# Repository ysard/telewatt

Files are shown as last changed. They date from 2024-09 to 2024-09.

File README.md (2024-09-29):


[][cc-by-nc-sa]

# TeleWatt

## Projet et avant-propos

Ce circuit a pour but de traiter les informations émises depuis
la sortie Télé-Information Client (TIC) des compteurs
d'électricité installés par le fournisseur français Enedis.

La sortie TIC offre aux clients la possibilité d’être informés en temps réel
des grandeurs électriques mesurées (périodes tarifaires, contacts virtuels,
puissance instantanée, etc.).

Ce système avec son firmware interprète les données, les conserve sur un ESP8266
et/ou les envoie sur un serveur personnel. Ceci garantit une pleine maîtrise
de celles-ci sans passer par un prestataire **coûteux** et parfois opaque.

Par ailleurs, les pas de collecte de 1h ou 30 minutes sont déjà particulièrement
intrusifs s'ils ont été souscrits auprès du fournisseur.
Un pas de collecte plus court permit par les modules Téléinfo l'est encore plus.
Par ailleurs, les modules du commerce ne viennent en général jamais seuls :
ils peuvent être couplés à des mesures de température, d'humidité, etc.
Des économies sont promises, mais c'est surtout un profilage à l'usage de l'électricité
qui est obtenu.

## Circuit

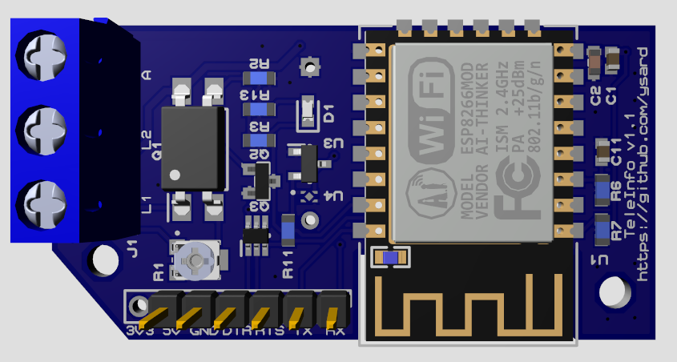
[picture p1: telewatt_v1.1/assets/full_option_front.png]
v1.1 front


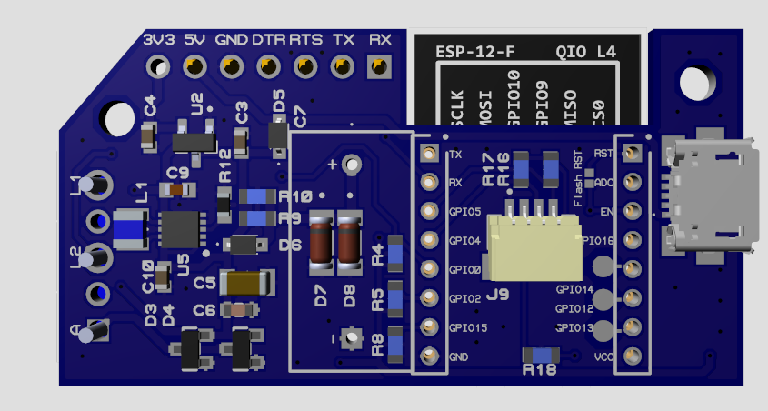
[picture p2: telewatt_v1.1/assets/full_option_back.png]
v1.1 back

Carte complète (circuit USB + condensateur; en pratique, un seul est nécessaire).

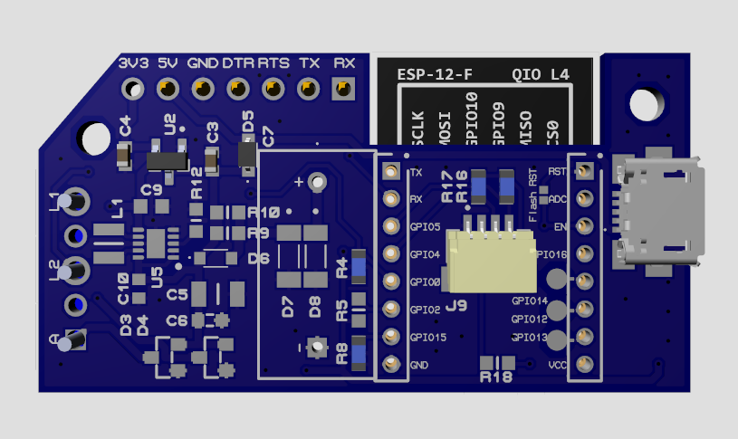
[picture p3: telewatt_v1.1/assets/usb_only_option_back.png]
v1.1 usb only


Carte non autonome avec circuit USB seul.

### Généralités

Le raccordement se fait sur le bornier du compteur comprenant 3 bornes (L1, L2, A).
La borne A permet la conception de circuits autoalimentés à l'aide d'un
super condensateur garantissant une certaine autonomie (mais pas un fonctionnement continu).

Les anciens compteurs avec seulement les bornes L1 et L2 sont compatibles,
à condition d'opter pour la version du circuit requérant une alimentation externe (USB - 5V).

La carte se charge à 100% en 11 minutes et autorise 4 minutes d'autonomie
avec un condensateur de 3.5F.
Un tel condensateur est très largement surdimensionné pour une brève
connexion MQTT toutes les 5 minutes.

Les composants sont choisis pour être courants, peu coûteux et faciles
à utiliser lors d'un assemblage manuel.

### Fonctionnalités

- ESP8266 1Mb ou 4Mb
- Autoalimenté
- Veille profonde
- Suivi de tension du condensateur
- Broches UART accessibles : GND, 3V3, 5V, RX, TX, DTR, RST
(Notes : **ne pas utiliser simultanément les broches 3V3 et 5V**; la broche 3V3 **n'est pas protégée**; bien veiller à fournir cette tension exacte en cas d'utilisation).
- GPIOs exposés : 12, 13, 14
- Connexion au compteur via un bornier ou des broches

Options :

- LED optionnelle pour visualiser la réception Téléinfo
(couper la piste droite du pad "Auto TIC LED", et souder le pad central avec celui de gauche).
- Emplacement QWIIC I2C
- Circuit d'alimentation USB

### Pinout

Pin     | Fonction
|:--- |:--- |
ADC     | Surveillance de la tension du condensateur
GPIO0   | Démarrage automatique en mode flash
GPIO1   | UART TX
GPIO2   | Résistance de Pull-up / tirage
GPIO3   | UART RX / Téléinfo RX
GPIO4   | I2C SDA
GPIO5   | I2C SCL
GPIO7   | Correctif optionnel deepsleep pour ESP8266 [défaillants](https://github.com/esp8266/Arduino/issues/6007)
GPIO12  | Pad libre
GPIO13  | Pad libre
GPIO14  | Gestion optionnelle de la LED TIC, pad libre
GPIO15  | Résistance de Pull-down / rappel
GPIO16  | Réveil deepsleep

### Datasheet

python test coverage

### Historique des changements

#### v1.1

- Réduction de la taille: passe entièrement dans la coque du Linky
- Ajout R18: Correctif ESP8266 défaillants sur le PCB
- Correction du circuit de flash automatique non fonctionnel
- Suppression connecteur Mini-USB
- Doublement optionnel des zener D7-D8
- Pad optionnel de gestion de la LED TIC
- Pad optionnel de gestion du flash sur le pin RST au lieu du pin EN
- Ajout broche 5V
- Ajout circuit de surveillance de la tension du condensateur

## Firmware

Le circuit est compatible avec l'extension Teleinfo de Tasmota :
[Tasmota - Teleinfo](https://tasmota.github.io/docs/Teleinfo/).

Mais aussi avec une version non officielle améliorée :
<https://github.com/NicolasBernaerts/tasmota/tree/master/teleinfo)>.

ESPHome est probablement aussi supporté.

Tous ces firmwares sont compatibles avec HomeAssistant.

### Procédure de flash

Matériel requis : interface USB vers TTL/UART.
Exemples de chipsets : CH341 CH340, CP2102, FT232RL, etc.

Installation d'`esptool` via le gestionnaire système ou Python :

    $ apt install esptool

ou :

    $ pip install esptool

Envoi du binaire (pré)compilé :

    $ esptool write_flash -fs 4MB -fm dout 0x0 tasmota-teleinfo-**.bin

Où `**` correspond au type d'ESP8266 utilisé (normalement 4M).
Toutefois pour un usage avec HomeAssistant, les options incluses dans cette version
(courbes et historique) sont inutiles; opter pour la version 1M
ou une compilation personnalisée est donc envisageable.

Les mises à jour ultérieures pourront se faire en ligne (Over The Air - OTA).

## Configuration

Voici l'essentiel des modifications pour Tasmota + HomeAssistant.

Pour plus d'informations, voir les documentations complètes des firmwares respectifs :

- https://tasmota.github.io/docs/Teleinfo/#configure-gpios-for-teleinfo
- https://github.com/NicolasBernaerts/tasmota/tree/master/teleinfo#fonctionnalit%C3%A9s

Dès le branchement, l'ESP8266 démarre en mode configuration WiFi.
Si le condensateur est chargé, quelques minutes seront octroyées
pour faire les modifications requises.

### Configuration du WiFi

Sélectionner le point d'accès initié par le module et s'y connecter avec
un ordinateur ou un téléphone.

L'adresse de la page de configuration est `http://192.168.4.1`.
Renseigner le mot de passer réseau puis laisser l'appareil redémarrer.

### Configuration du module

Se connecter à l'appareil depuis le réseau WiFi du domicile
(rechercher son  adresse IP via les pages d'administration de la box
ou via `nmap -sP 192.168.1.0/24`).

Ne pas oublier de configurer la liaison MQTT (IP, port, login, mot de passe),
la connexion réseau (une IP fixe limite le temps passé hors veille)
et les options Téléinfo (mode standard vs historique, etc.).

L'essentiel des configurations se fait dans la console Tasmota.

Pour configurer les GPIOs et le type de module simplement en une fois, voici le
[template à importer](https://tasmota.github.io/docs/Templates/#importing-templates) :

    {"NAME":"TeleWatt","GPIO":[1,1,1,5152,1,1,1,1,1,1,1,1,1,1],"FLAG":0,"BASE":18}

- Configuration du type de module :
Type de module : "Generic(18)" (i.e remplacer "Generic (0)")

- Configuration des GPIOs :

    - Config données: GPIO3 (RXD) = "TInfo RX"
    - Config deepsleep: GPIO16 = "None"

- Activer l'auto-découverte des entités HomeAssistant :

    $ hass_enable 1

- Désactiver le serveur TCP :

    $ tcp_stop

- Désactiver l'affichage des données sur la page d'accueil :

    $ websensor3 0

- Durée de mise en sommeil (le module entrera en veille 60s après cette commande) :

    $ deepsleeptime xxx   (<= ~30s, != 300s)

## Autre documentation

La démodulation Téléinfo est tirée du travail de Charles Hallard :

- [Démystifier le décodage Téléinformation](http://hallard.me/demystifier-la-teleinfo/)
- [Récupérer les données de son compteur linky](https://miniprojets.net/index.php/2019/06/28/recuperer-les-donnees-de-son-compteur-linky/)

## Licence

L'interface matérielle est publiée sous licence [Creative Commons CC BY-NC-SA 4.0][cc-by-nc-sa].

[cc-by-nc-sa]: http://creativecommons.org/licenses/by-nc-sa/4.0/
[cc-by-nc-sa-image]: https://licensebuttons.net/l/by-nc-sa/4.0/88x31.png
[cc-by-nc-sa-shield]: https://img.shields.io/badge/License-CC%20BY--NC--SA%204.0-lightgrey.svg

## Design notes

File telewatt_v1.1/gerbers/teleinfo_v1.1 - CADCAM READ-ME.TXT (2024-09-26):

LABCENTER PROTEUS TOOL INFORMATION FILE
=======================================

In case of difficulty, please e-mail support@labcenter.co.uk

Tool set up for Proteus layout 'teleinfo_v1.1.pdsprj'.
CADCAM generated at 18:34:03 on jeudi 26 septembre 2024.

File List
---------
Top Copper              : teleinfo_v1.1 - CADCAM Top Copper.GBR
Bottom Copper           : teleinfo_v1.1 - CADCAM Bottom Copper.GBR
Mechanical 1            : teleinfo_v1.1 - CADCAM Mechanical 1.GBR
Top Silk Screen         : teleinfo_v1.1 - CADCAM Top Silk Screen.GBR
Bottom Silk Screen      : teleinfo_v1.1 - CADCAM Bottom Silk Screen.GBR
Top Solder Resist       : teleinfo_v1.1 - CADCAM Top Solder Resist.GBR
Bottom Solder Resist    : teleinfo_v1.1 - CADCAM Bottom Solder Resist.GBR
Top SMT Paste           : teleinfo_v1.1 - CADCAM Top SMT Paste.GBR
Bottom SMT Paste        : teleinfo_v1.1 - CADCAM Bottom SMT Paste.GBR
Top Assembly            : teleinfo_v1.1 - CADCAM Top Assembly.GBR
Bottom Assembly         : teleinfo_v1.1 - CADCAM Bottom Assembly.GBR
Profile                 : teleinfo_v1.1 - CADCAM Profile.GBR
Drill, Unplated, 1-16   : teleinfo_v1.1 - CADCAM Drill TOP-BOT NonPlated.GBR
Drill, Plated, 1-16     : teleinfo_v1.1 - CADCAM Drill TOP-BOT Plated.GBR
Drill, Filled, 1-16     : teleinfo_v1.1 - CADCAM Drill TOP-BOT Filled and Plated.GBR
Netlist                 : teleinfo_v1.1 - CADCAM Netlist.IPC

Photoplotter Setup
------------------
Format: X2, ASCII, 4.3, metric, absolute, eob=*, LZO
Bounds: -6.72mm 6.16mm 17.89mm 53.37mm
Notes:  D=Diameter, S=Side, W=Width, H=Height, C=Chamfer, I=Index

D10	CIRCLE  D=0.254mm                                                         DRAW  Conductor
D11	CIRCLE  D=0.508mm                                                         DRAW  Conductor
D12	CIRCLE  D=0.305mm                                                         DRAW  Conductor
D13	CIRCLE  D=0.203mm                                                         DRAW  Conductor
D14	CIRCLE  D=0.6mm                                                           FLASH ViaPad
D15	RECT    W=1.2mm               H=2mm                                       FLASH SMDPad,CuDef
D16	RECT    W=2mm                 H=1.2mm                                     FLASH SMDPad,CuDef
D17	SQUARE  S=1.485mm                                                         FLASH ComponentPad
D18	CIRCLE  D=2.1mm                                                           FLASH ComponentPad
D19	RECT    W=2.1mm               H=1.45mm                                    FLASH SMDPad,CuDef
D70	RECT    W=0.889mm             H=1.016mm                                   FLASH SMDPad,CuDef
D71	RECT    W=0.991mm             H=0.94mm                                    FLASH SMDPad,CuDef
D20	RECT    W=0.94mm              H=0.991mm                                   FLASH SMDPad,CuDef
D21	RECT    W=0.81mm              H=0.94mm                                    FLASH SMDPad,CuDef
D22	SQUARE  S=0.889mm                                                         FLASH SMDPad,CuDef
D23	RECT    W=0.6mm               H=1.25mm                                    FLASH SMDPad,CuDef
D24	SQUARE  S=0.05mm                                                          FLASH SMDPad,CuDef
D25	PPAD    W=0.31mm              H=0.46mm              I=0                   FLASH SMDPad,CuDef
D26	PPAD    W=0.31mm              H=0.46mm              I=1                   FLASH SMDPad,CuDef
D27	PPAD    W=0.31mm              H=0.46mm              I=2                   FLASH SMDPad,CuDef
D28	PPAD    W=0.31mm              H=0.46mm              I=3                   FLASH SMDPad,CuDef
D29	PPAD    W=0.82mm              H=0.82mm              I=4                   FLASH SMDPad,CuDef
D72	CIRCLE  D=1.397mm                                                         FLASH ComponentPad
D73	SQUARE  S=1.397mm                                                         FLASH ComponentPad
D30	SQUARE  S=1.27mm                                                          FLASH ComponentPad
D31	CIRCLE  D=1.24mm                                                          FLASH ComponentPad
D32	SQUARE  S=1.2mm                                                           FLASH SMDPad,CuDef
D33	RECT    W=1.6mm               H=1.5mm                                     FLASH SMDPad,CuDef
D34	SQUARE  S=0.95mm                                                          FLASH SMDPad,CuDef
D35	CIRCLE  D=1.65mm                                                          FLASH OtherPad,Unknown
D36	RECT    W=1.15mm              H=0.45mm                                    FLASH SMDPad,CuDef
D37	SQUARE  S=1.65mm                                                          FLASH WasherPad
D38	CIRCLE  D=1.65mm                                                          FLASH ComponentPad
D39	RECT    W=0.9mm               H=1.3mm                                     FLASH SMDPad,CuDef
D40	RECT    W=1.3mm               H=0.9mm                                     FLASH SMDPad,CuDef
D41	CIRCLE  D=0.178mm                                                         DRAW  Profile
D42	CIRCLE  D=0.635mm                                                         DRAW  Conductor
D43	CIRCLE  D=0.381mm                                                         DRAW  Conductor
D44	PPAD    W=1.22mm              H=0.62mm              I=5                   FLASH SMDPad,CuDef
D45	RECT    W=1.13mm              H=1.72mm                                    FLASH SMDPad,CuDef
D46	RECT    W=0.9mm               H=0.8mm                                     FLASH SMDPad,CuDef
D47	PPAD    W=0.3mm               H=0.8mm               I=6                   FLASH SMDPad,CuDef
D48	PPAD    W=0.3mm               H=0.8mm               I=7                   FLASH SMDPad,CuDef
D49	RECT    W=2.1mm               H=1.3mm                                     FLASH SMDPad,CuDef
D50	RECT    W=1.02mm              H=0.96mm                                    FLASH SMDPad,CuDef
D51	RECT    W=0.9mm               H=0.95mm                                    FLASH SMDPad,CuDef
D52	RECT    W=1.82mm              H=1.05mm                                    FLASH SMDPad,CuDef
D53	RECT    W=0.85mm              H=2.2mm                                     FLASH SMDPad,CuDef
D54	RECT    W=0.8mm               H=0.9mm                                     FLASH SMDPad,CuDef
D55	RECT    W=0.4mm               H=1.35mm                                    FLASH SMDPad,CuDef
D56	RECT    W=2.1mm               H=1.6mm                                     FLASH SMDPad,CuDef
D57	RECT    W=1.8mm               H=1.9mm                                     FLASH SMDPad,CuDef
D58	SQUARE  S=1.9mm                                                           FLASH SMDPad,CuDef
D59	RECT    W=1.55mm              H=0.6mm                                     FLASH SMDPad,CuDef
D60	RECT    W=1.8mm               H=1.2mm                                     FLASH SMDPad,CuDef
D61	CIRCLE  D=1.5mm                                                           FLASH FiducialPad,Global
D62	CIRCLE  D=0.2mm                                                           DRAW  Material
D63	CIRCLE  D=0.178mm                                                         DRAW  Material
D64	CIRCLE  D=0.127mm                                                         DRAW  Material
D65	CIRCLE  D=0.127mm                                                         DRAW  NonMaterial
D66	CIRCLE  D=0.1mm                                                           DRAW  Material
D67	CIRCLE  D=0.076mm                                                         DRAW  NonMaterial
D68	CIRCLE  D=0.25mm                                                          DRAW  Material
D69	PPAD    W=1.2mm               H=2mm                 I=8                   FLASH Material
D74	PPAD    W=2mm                 H=1.2mm               I=9                   FLASH Material
D75	PPAD    W=1.585mm             H=1.585mm             I=10                  FLASH Material
D76	CIRCLE  D=2.2mm                                                           FLASH Material
D77	PPAD    W=2.1mm               H=1.45mm              I=11                  FLASH Material
D78	PPAD    W=1.143mm             H=1.27mm              I=12                  FLASH Material
D79	PPAD    W=0.991mm             H=0.94mm              I=13                  FLASH Material
D80	PPAD    W=0.94mm              H=0.991mm             I=14                  FLASH Material
D81	PPAD    W=0.81mm              H=0.94mm              I=15                  FLASH Material
D82	PPAD    W=1.143mm             H=1.143mm             I=16                  FLASH Material
D83	PPAD    W=0.6mm               H=1.25mm              I=17                  FLASH Material
D84	PPAD    W=0.05mm              H=0.05mm              I=18                  FLASH Material
D85	CIRCLE  D=1.651mm                                                         FLASH Material
D86	PPAD    W=1.651mm             H=1.651mm             I=19                  FLASH Material
D87	PPAD    W=1.524mm             H=1.524mm             I=20                  FLASH Material
D88	CIRCLE  D=1.34mm                                                          FLASH Material
D89	PPAD    W=1.2mm               H=1.2mm               I=21                  FLASH Material
D90	PPAD    W=1.6mm               H=1.5mm               I=22                  FLASH Material
D91	PPAD    W=0.95mm              H=0.95mm              I=23                  FLASH Material
D92	CIRCLE  D=1.65mm                                                          FLASH Material
D93	PPAD    W=1.15mm              H=0.45mm              I=24                  FLASH Material
D94	PPAD    W=1.65mm              H=1.65mm              I=25                  FLASH Material
D95	PPAD    W=0.9mm               H=1.3mm               I=26                  FLASH Material
D96	PPAD    W=1.3mm               H=0.9mm               I=27                  FLASH Material
D97	CIRCLE  D=0.025mm                                                         DRAW  Material
D98	PPAD    W=0.94mm              H=0.991mm             I=28                  FLASH Material
D99	PPAD    W=1.143mm             H=1.27mm              I=29                  FLASH Material
D100	PPAD    W=1.22mm              H=0.62mm              I=5                   FLASH Material
D101	PPAD    W=0.81mm              H=0.94mm              I=30                  FLASH Material
D102	PPAD    W=1.143mm             H=1.143mm             I=31                  FLASH Material
D103	PPAD    W=0.991mm             H=0.94mm              I=32                  FLASH Material
D104	PPAD    W=1.13mm              H=1.72mm              I=33                  FLASH Material
D105	PPAD    W=0.9mm               H=0.8mm               I=34                  FLASH Material
D106	PPAD    W=0.3mm               H=0.8mm               I=6                   FLASH Material
D107	PPAD    W=0.3mm               H=0.8mm               I=7                   FLASH Material
D108	PPAD    W=2.1mm               H=1.3mm               I=35                  FLASH Material
D109	PPAD    W=1.02mm              H=0.96mm              I=36                  FLASH Material
D110	PPAD    W=0.9mm               H=0.95mm              I=37                  FLASH Material
D111	PPAD    W=1.82mm              H=1.05mm              I=38                  FLASH Material
D112	PPAD    W=0.85mm              H=2.2mm               I=39                  FLASH Material
D113	PPAD    W=0.8mm               H=0.9mm               I=40                  FLASH Material
D114	PPAD    W=0.4mm               H=1.35mm              I=41                  FLASH Material
D115	PPAD    W=2.1mm               H=1.6mm               I=42                  FLASH Material
D116	PPAD    W=1.8mm               H=1.9mm               I=43                  FLASH Material
D117	PPAD    W=1.9mm               H=1.9mm               I=44                  FLASH Material
D118	PPAD    W=1.55mm              H=0.6mm               I=45                  FLASH Material
D119	PPAD    W=1.8mm               H=1.2mm               I=46                  FLASH Material
D120	CIRCLE  D=2.516mm                                                         FLASH Material
D121	RECT    W=1.2mm               H=2mm                                       FLASH Material
D122	RECT    W=2mm                 H=1.2mm                                     FLASH Material
D123	RECT    W=2.1mm               H=1.45mm                                    FLASH Material
D124	RECT    W=0.889mm             H=1.016mm                                   FLASH Material
D125	RECT    W=0.991mm             H=0.94mm                                    FLASH Material
D126	RECT    W=0.94mm              H=0.991mm                                   FLASH Material
D127	RECT    W=0.81mm              H=0.94mm                                    FLASH Material
D128	SQUARE  S=0.889mm                                                         FLASH Material
D129	RECT    W=0.6mm               H=1.25mm                                    FLASH Material
D130	SQUARE  S=0.05mm                                                          FLASH Material
D131	SQUARE  S=1.2mm                                                           FLASH Material
D132	RECT    W=1.6mm               H=1.5mm                                     FLASH Material
D133	SQUARE  S=0.95mm                                                          FLASH Material
D134	RECT    W=1.15mm              H=0.45mm                                    FLASH Material
D135	RECT    W=0.9mm               H=1.3mm                                     FLASH Material
D136	RECT    W=1.3mm               H=0.9mm                                     FLASH Material
D137	PPAD    W=1.22mm              H=0.62mm              I=47                  FLASH Material
D138	RECT    W=1.13mm              H=1.72mm                                    FLASH Material
D139	RECT    W=0.9mm               H=0.8mm                                     FLASH Material
D140	PPAD    W=0.3mm               H=0.8mm               I=48                  FLASH Material
D141	PPAD    W=0.3mm               H=0.8mm               I=49                  FLASH Material
D142	RECT    W=2.1mm               H=1.3mm                                     FLASH Material
D143	RECT    W=1.02mm              H=0.96mm                                    FLASH Material
D144	RECT    W=0.9mm               H=0.95mm                                    FLASH Material
D145	RECT    W=1.82mm              H=1.05mm                                    FLASH Material
D146	RECT    W=0.85mm              H=2.2mm                                     FLASH Material
D147	RECT    W=0.8mm               H=0.9mm                                     FLASH Material
D148	RECT    W=0.4mm               H=1.35mm                                    FLASH Material
D149	RECT    W=2.1mm               H=1.6mm                                     FLASH Material
D150	RECT    W=1.8mm               H=1.9mm                                     FLASH Material
D151	SQUARE  S=1.9mm                                                           FLASH Material
D152	RECT    W=1.55mm              H=0.6mm                                     FLASH Material
D153	RECT    W=1.8mm               H=1.2mm                                     FLASH Material
D154	CIRCLE  D=0.8mm                                                           DRAW  Material
D155	CIRCLE  D=0.688mm                                                         DRAW  Material
D156	CIRCLE  D=0.05mm                                                          DRAW  Material
D157	CIRCLE  D=0.594mm                                                         DRAW  Material
D158	CIRCLE  D=0.224mm                                                         DRAW  Material
D159	CIRCLE  D=0.84mm                                                          DRAW  Material
D160	CIRCLE  D=0.314mm                                                         DRAW  Material
D161	CIRCLE  D=0.406mm                                                         DRAW  Material
D162	CIRCLE  D=0.097mm                                                         DRAW  Material
D163	CIRCLE  D=0.396mm                                                         DRAW  Material
D164	CIRCLE  D=0.067mm                                                         DRAW  Material
D165	CIRCLE  D=0.376mm                                                         DRAW  Material
D166	CIRCLE  D=0.052mm                                                         DRAW  Material
D167	CIRCLE  D=0.356mm                                                         DRAW  Material
D168	CIRCLE  D=0.057mm                                                         DRAW  Material
D169	CIRCLE  D=0.5mm                                                           DRAW  Material
D170	CIRCLE  D=0.114mm                                                         DRAW  Material
D171	CIRCLE  D=0.02mm                                                          DRAW  Material
D172	CIRCLE  D=0.046mm                                                         DRAW  Material
D173	CIRCLE  D=0.17mm                                                          DRAW  Material
D174	CIRCLE  D=0.48mm                                                          DRAW  Material
D175	CIRCLE  D=0.164mm                                                         DRAW  Material
D176	CIRCLE  D=0.38mm                                                          DRAW  Material
D177	CIRCLE  D=0.07mm                                                          DRAW  Material
D178	CIRCLE  D=0.405mm                                                         DRAW  Material
D179	CIRCLE  D=0.086mm                                                         DRAW  Material
D180	CIRCLE  D=0.66mm                                                          DRAW  Material
D181	CIRCLE  D=0.201mm                                                         DRAW  Material
D182	CIRCLE  D=0.488mm                                                         DRAW  Material
D183	CIRCLE  D=0.108mm                                                         DRAW  Material
D184	CIRCLE  D=0.559mm                                                         DRAW  Material
D185	CIRCLE  D=0.415mm                                                         DRAW  Material
D186	CIRCLE  D=0.123mm                                                         DRAW  Material
D187	CIRCLE  D=0.36mm                                                          DRAW  Material
D188	CIRCLE  D=0.113mm                                                         DRAW  Material
D189	CIRCLE  D=0.27mm                                                          DRAW  Material
D190	CIRCLE  D=0.099mm                                                         DRAW  Material
D191	CIRCLE  D=0.408mm                                                         DRAW  Material
D192	CIRCLE  D=0.064mm                                                         DRAW  Material
D193	CIRCLE  D=0.065mm                                                         DRAW  Material
D194	CIRCLE  D=0.728mm                                                         DRAW  Material
D195	CIRCLE  D=0.098mm                                                         DRAW  Material
D196	CIRCLE  D=0.765mm                                                         DRAW  Material
D197	CIRCLE  D=0.137mm                                                         DRAW  Material
D198	CIRCLE  D=0.54mm                                                          DRAW  Material
D199	CIRCLE  D=0.237mm                                                         DRAW  Material
D200	CIRCLE  D=2.5mm                                                           FLASH MechanicalDrill
D201	CIRCLE  D=0.3mm                                                           FLASH ViaDrill
D202	CIRCLE  D=1.397mm                                                         FLASH ComponentDrill
D203	CIRCLE  D=0.813mm                                                         FLASH ComponentDrill
D204	CIRCLE  D=0.889mm                                                         FLASH ComponentDrill
D205	CIRCLE  D=1.1mm                                                           FLASH OtherDrill,Unknown
D206	CIRCLE  D=1.1mm                                                           FLASH ComponentDrill

Layer Stackup
-------------
Top Solder Resist        : 0.01mm     Resist
Top Copper               : 0.018mm    Copper
Core                     : 1.55mm     FR4
Bottom Copper            : 0.018mm    Copper
Bottom Solder Resist     : 0.01mm     Resist

[END OF FILE]

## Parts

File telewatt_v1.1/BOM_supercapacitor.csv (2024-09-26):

Category | References | Value | Stock Code
Capacitors | C1 | 10u | JMK107ABJ106MA-T/GRM188R60J106ME47D
Capacitors | C2 | 100n | 0603YC104K4T4A
Capacitors | C5 | 100uf | CL31A107MQHNNWE
Capacitors | C6 | 100n | 0603YC104K4T4A
Capacitors | C7 | DGH155Q5R5 | DGH155Q5R5
Capacitors | C9 | 22u | GRM188R60J226MEA0D/GRM187R60J226ME15D
Capacitors | C10 | 10u | JMK107ABJ106MA-T/GRM188R60J106ME47D
Capacitors | C11 | 10u | JMK107ABJ106MA-T/GRM188R60J106ME47D
Resistors | R1 | TC33X-2-202E | TC33X-2-202E
Resistors | R2 | 3.3K | RMC1/16K3301FTP
Resistors | R3 | 10K | RMC1/16-1002FTP
Resistors | R4 | 10K | RMC1/16-1002FTP
Resistors | R7 | 10K | RMC1/16-1002FTP
Resistors | R8 | 10K | RMC1/16-1002FTP
Resistors | R9 | 10 | 10
Resistors | R10 | 10 | 10
Resistors | R11 | 10K | RMC1/16-1002FTP
Resistors | R12 | 36.5K | CR0603-FX-3652ELF
Resistors | R13 | 18K | 18K
Resistors | R16 | 4.7K | 4.7K
Resistors | R17 | 4.7K | 4.7K
Resistors | R19 | 470K | 470K
Resistors | R20 | 470K | 470K
Integrated Circuits | U1 | ESP12F | ESP12F
Integrated Circuits | U3 | TPS3839K33DBZR | TPS3839K33DBZR
Integrated Circuits | U5 | TSP63900 | TPS63900DSKR
Transistors | Q1 | LTV-814S-TA1 | LTV-814S-TA1
Transistors | Q2 | BSS138 | BSS138
Transistors | Q3 | UMH3N-TP | UMH3N-TP
Diodes | D1 | RED LED
Diodes | D3 | BAT54S | BAT54S
Diodes | D4 | BAT54S | BAT54S
Diodes | D6 | CUS10S30_H3F | CUS10S30,H3F
Diodes | D7 | 5.1V | ZMM5.1
Diodes | D8 | 5.1V | ZMM5.1
Miscellaneous | J1 | KF3012P | bornier
Miscellaneous | J2 | KF3012P | bornier
Miscellaneous | J3 | MTMM10808LS300
Miscellaneous | J4 | MTMM10808LS300
Miscellaneous | J5 | HEADER 7PIN-G-V-TH
Miscellaneous | J9 | PRT14417
Miscellaneous | L1 | DFE252012F-2R2M=P2 | DFE252012F-2R2M=P2

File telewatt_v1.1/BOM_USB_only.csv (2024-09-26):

Category | References | Value | Stock Code
Capacitors | C1 | 10u | JMK107ABJ106MA-T/GRM188R60J106ME47D
Capacitors | C2 | 100n | 0603YC104K4T4A
Capacitors | C3 | 1.0u | JMK107BJ105MA-T
Capacitors | C4 | 1.0u | JMK107BJ105MA-T
Capacitors | C11 | 10u | JMK107ABJ106MA-T/GRM188R60J106ME47D
Resistors | R1 | TC33X-2-202E | TC33X-2-202E
Resistors | R2 | 3.3K | RMC1/16K3301FTP
Resistors | R3 | 10K | RMC1/16-1002FTP
Resistors | R4 | 10K | RMC1/16-1002FTP
Resistors | R7 | 10K | RMC1/16-1002FTP
Resistors | R8 | 10K | RMC1/16-1002FTP
Resistors | R11 | 10K | RMC1/16-1002FTP
Resistors | R13 | 18K | 18K
Resistors | R14 | 5.1K | 5.1K
Resistors | R15 | 5.1K | 5.1K
Resistors | R16 | 4.7K | 4.7K
Resistors | R17 | 4.7K | 4.7K
Resistors | R19 | 470K | 470K
Resistors | R20 | 470K | 470K
Integrated Circuits | U1 | ESP12F | ESP12F
Integrated Circuits | U2 | MCP1700T3302E_TT | MCP1700T-3302E/TT
Integrated Circuits | U3 | TPS3839K33DBZR | TPS3839K33DBZR
Transistors | Q1 | LTV-814S-TA1 | LTV-814S-TA1
Transistors | Q2 | BSS138 | BSS138
Transistors | Q3 | UMH3N-TP | UMH3N-TP
Diodes | D1 | RED LED
Diodes | D5 | CUS10S30_H3F | CUS10S30,H3F
Miscellaneous | J1 | KF3012P | bornier
Miscellaneous | J2 | KF3012P | bornier
Miscellaneous | J3 | MTMM10808LS300
Miscellaneous | J4 | MTMM10808LS300
Miscellaneous | J5 | HEADER 7PIN-G-V-TH
Miscellaneous | J8 | micro USB
Miscellaneous | J9 | PRT14417

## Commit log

2024-09-26 [1.1] Add BOM + schematic
    [BOM_USB_only.csv, BOM_supercapacitor.csv]
2024-09-26 [1.1] Add gerber files
    [teleinfo_v1.1 - CADCAM Bottom Assembly.GBR, teleinfo_v1.1 - CADCAM Bottom Copper.GBR, teleinfo_v1.1 - CADCAM Bottom SMT Paste.GBR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]
2024-09-26 [readme] Add text about TIC LED option pad
2024-09-26 [readme] Add schematic img
2024-09-26 [readme] Add 3D captures; fix schematic img markdown
2024-09-26 [1.0] Add schematic
2024-09-26 [readme] add note about 3V3 + 5V pin usage
2026-06-01 Update schematic - fix positions - fix values of the resistor divider: match with the esp8266 ADC max value of 1V
